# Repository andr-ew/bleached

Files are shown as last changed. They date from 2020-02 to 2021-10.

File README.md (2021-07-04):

## bleached
small/inexpensive 7-knob teensy midi controller. 

many thanks to [brian crabtree](https://vimeo.com/134631071) for sending me the original design & helping me add the teensy !!

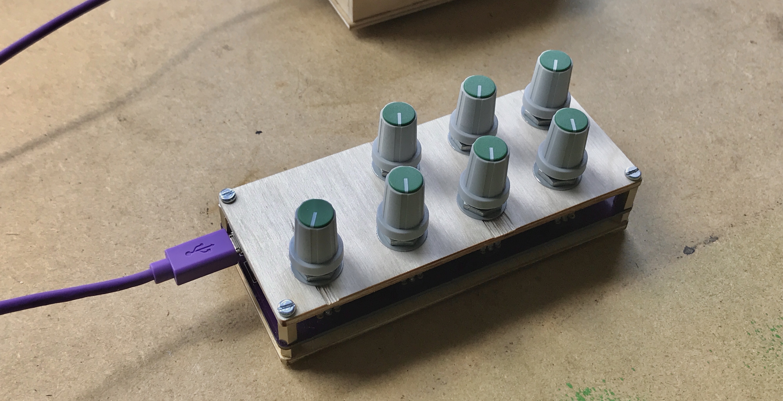
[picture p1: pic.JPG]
product image


## BOM

- [full BOM other than knobs](https://octopart.com/bom-tool/u6LfSTSI)
- [knobs from thonk (uk)](https://www.thonk.co.uk/shop/intellijel-black-knobs/) - [caps](https://www.thonk.co.uk/shop/sifam-caps/)

## Build

start with soldering all header pins to the underside of the teensy 3.2, reference the pic below for placement. the goal is to hit all of the power/ground pinouts along with the analog ins. solder short sides the two through-hole pins to the teensy. 

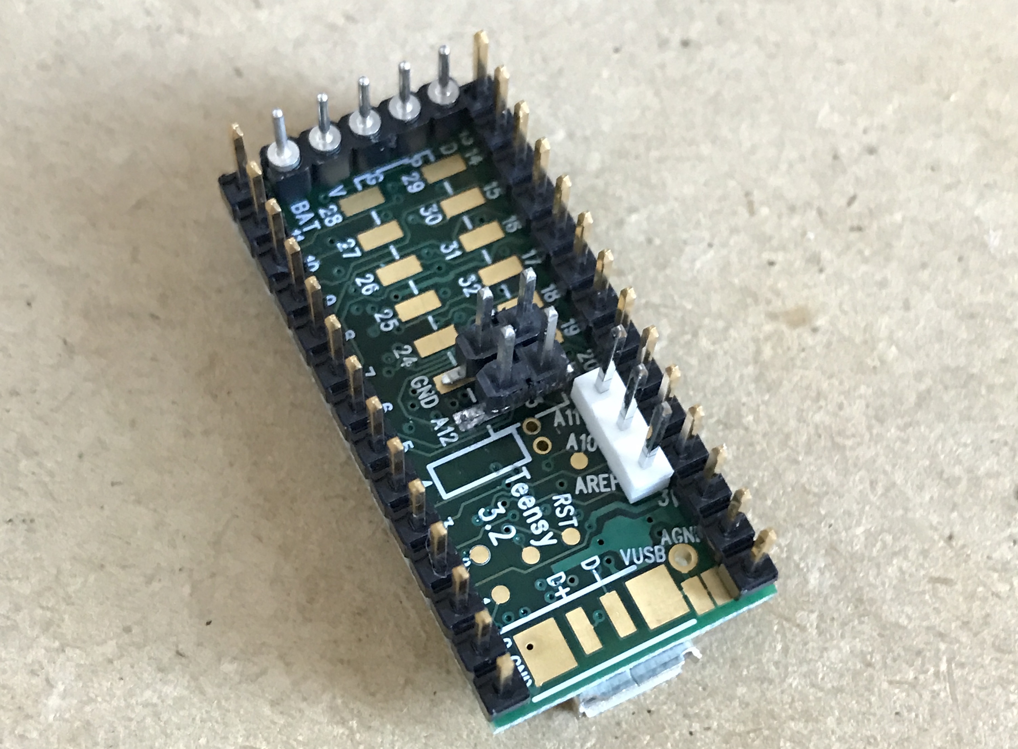
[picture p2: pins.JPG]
pins image


getting the surface mount pins in the right place is the trickiest part of this project. start with those (one leg at a time), use tweezers, and test placement on the board with the through-hole headers.

the rest should be pretty easy, solder all the other headers to the teensy, solder the teensy to the board (on the top / stencil side of the board), and solder every leg of each of the pots. load firmware & test once everything is soldered (although, at this point there's kinda no going back) - you can test your pots by loading the [test_inputs](./firmware/test_inputs/test_inputs.ino) sketch onto the board, and looking at the serial monitor window (Tools -> Serial Monitor) while twiddling the knobs. the firmware is an arduino project for use with [teensyduino](https://www.pjrc.com/teensy/teensyduino.html). 

next, add the metal standoffs, shorter ones on the bottom, taller ones on top. then screw in the panels. if you want the pots extra stable you can add the nuts and washers that come with the potentiometers. then plop on yr favorite knobs & yr golden !

## FAQ

q1) i don't have a 5-pin header for the top end of the teensy.
a2) you should have a 3-pin header, which should be used with the 3 middle pins.

q2) i get an error compiling the firmware, `'usbMIDI' was not declared in this scope`.
a2) set the USB type to 'Serial + MIDI' on the Tools -> USB Type menu.

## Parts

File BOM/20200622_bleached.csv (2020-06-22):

Qty | Line Item | Manufacturer | MPN | Octopart URL | Schematic Reference | Internal Part Number | Description | Total Qty (@ Batch Size: 1) | SKU | SKU | Packaging | Packaging | Unit Price (@ Batch Size: 1) | Unit Price (@ Batch Size: 1) | In Stock | In Stock | MOQ | MOQ | URL | URL | Distributor [Lowest Price (Overall)] | SKU [Lowest Price (Overall)] | Packaging [Lowest Price (Overall)] | Unit Price (@ Batch Size: 1) [Lowest Price (Overall)] | Line Total [Lowest Price (Overall)] | Batch Total [Lowest Price (Overall)] | In Stock [Lowest Price (Overall)] | MOQ [Lowest Price (Overall)] | URL [Lowest Price (Overall)] | Notes
 |  |  |  |  |  |  |  |  | Digi-Key | Mouser | Digi-Key | Mouser | Digi-Key | Mouser | Digi-Key | Mouser | Digi-Key | Mouser | Digi-Key | Mouser
1 | DEV-13736 | SparkFun | DEV-13736 | https://octopart.com/dev-13736-sparkfun-66786793 |  |  | teensy | 1 | 1568-1231-ND | 474-DEV-13736 | Bulk |  | 21.88 | 22.5 | 3468 | 0 | 1 | 1 | https://octopart.com/click/track?ai=8237&sig=0cd337c&sid=459&ppid=66786793&vpid=238615722&ct=offers | https://octopart.com/click/track?c=1&ai=8237&sig=036cc5a&sid=2401&ppid=66786793&vpid=460594265&ct=offers | Arrow.cn | DEV13736#SPARKFUN |  | 21.75 | 21.75 | 21.75 | 243 | 1 | https://octopart.com/click/track?ai=8237&sig=0c83821&sid=28928&ppid=66786793&vpid=617625825&ct=offers
2 | 22-28-4143 | Molex | 22-28-4143 | https://octopart.com/22-28-4143-molex-278217 |  |  | teensy header | 2 | WM50016-14-ND | 538-22-28-4143 | Bulk | Bulk | 0.99 | 0.76 | 528 | 87 | 1 | 1 | https://octopart.com/click/track?ai=8237&sig=0a93492&sid=459&ppid=278217&vpid=78026483&ct=offers | https://octopart.com/click/track?ai=8237&sig=0809279&sid=2401&ppid=278217&vpid=37674059&ct=offers | Heilind Electronics | MOL22-28-4143 |  | 0.43008 | 0.86016 | 0.86016 | 40 | 1 | https://octopart.com/click/track?ai=8237&sig=0ffd42f&sid=8539&ppid=278217&vpid=20581064&ct=offers
7 | RK09L1140A2U | ALPS | RK09L1140A2U | https://octopart.com/rk09l1140a2u-alps-7850070 |  |  | 6mm pots | 7 |  | 688-RK09L1140A2U |  | Tray |  | 1.49 |  | 959 |  | 1 |  | https://octopart.com/click/track?ai=8237&sig=0f03634&sid=2401&ppid=7850070&vpid=37992684&ct=offers | LCSC | C470448 | Tray | 1.015 | 7.1049999999999995 | 7.1049999999999995 | 36 | 1 | https://octopart.com/click/track?ai=8237&sig=06be386&sid=27971&ppid=7850070&vpid=625387208&ct=offers
1 | TSM-102-01-T-DV | Samtec | TSM-102-01-T-DV | https://octopart.com/tsm-102-01-t-dv-samtec-6823736 |  |  | teensy header | 1 | SAM10784-ND | 200-TSM10201TDV | Bulk | Bulk | 0.39 | 0.39 | 1554 | 2391 | 1 | 1 | https://octopart.com/click/track?ai=8237&sig=0a25a83&sid=459&ppid=6823736&vpid=417407955&ct=offers | https://octopart.com/click/track?ai=8237&sig=05d727c&sid=2401&ppid=6823736&vpid=493282502&ct=offers | Newark | 77P4639 |  | 0.118 | 0.118 | 0.118 | 2673 | 1 | https://octopart.com/click/track?ai=8237&sig=03440e8&sid=2402&ppid=6823736&vpid=47139229&ct=offers
2 | 22-03-2031 | Molex | 22-03-2031 | https://octopart.com/22-03-2031-molex-15103 |  |  | teensy header | 2 | 900-0022032031-ND | 538-22-03-2031 | Bulk | Bulk | 0.28 | 0.28 | 0 | 13233 | 1 | 1 | https://octopart.com/click/track?c=1&ai=8237&sig=093f6bf&sid=459&ppid=15103&vpid=587828796&ct=offers | https://octopart.com/click/track?ai=8237&sig=05e84a0&sid=2401&ppid=15103&vpid=37607239&ct=offers | Newark | 26H0648 |  | 0.086 | 0.172 | 0.172 | 9190 | 1 | https://octopart.com/click/track?ai=8237&sig=07890cb&sid=2402&ppid=15103&vpid=2936454&ct=offers
1 | M80-2260000B | Harwin | M80-2260000B | https://octopart.com/m80-2260000b-harwin-81780540 |  |  | bag of 12 2.5mm screws (need 8 ) | 1 | M80-2260000B-ND | 855-M80-2260000B | Bulk |  |  | 4.1 | 0 | 157 | 196 | 1 | https://octopart.com/click/track?c=1&ai=8237&sig=0720959&sid=459&ppid=81780540&vpid=519727817&ct=offers | https://octopart.com/click/track?ai=8237&sig=06e02d6&sid=2401&ppid=81780540&vpid=420857730&ct=offers | Mouser | 855-M80-2260000B |  | 4.1 | 4.1 | 4.1 | 157 | 1 | https://octopart.com/click/track?ai=8237&sig=06e02d6&sid=2401&ppid=81780540&vpid=420857730&ct=offers
4 | R25-1001002 | Harwin | R25-1001002 | https://octopart.com/r25-1001002-harwin-793354 |  |  | 10mm spacer | 4 | 952-2174-ND | 855-R25-1001002 | Bulk |  | 0.48 | 0.4 | 3373 | 2227 | 1 | 1 | https://octopart.com/click/track?ai=8237&sig=076609f&sid=459&ppid=793354&vpid=58220356&ct=offers | https://octopart.com/click/track?ai=8237&sig=0f1cbc1&sid=2401&ppid=793354&vpid=46536103&ct=offers | Newark | 99W9384 |  | 0.305 | 1.22 | 1.22 | 5478 | 1 | https://octopart.com/click/track?ai=8237&sig=06fc5f0&sid=2402&ppid=793354&vpid=90930922&ct=offers
4 | R25-3000502 | Harwin | R25-3000502 | https://octopart.com/r25-3000502-harwin-793850 |  |  | 5mm spacer | 4 | 952-3456-ND | 855-R25-3000502 | Bulk |  | 0.83 | 0.71 | 1584 | 3121 | 1 | 1 | https://octopart.com/click/track?ai=8237&sig=00d5341&sid=459&ppid=793850&vpid=417952346&ct=offers | https://octopart.com/click/track?ai=8237&sig=0a09265&sid=2401&ppid=793850&vpid=37615038&ct=offers | Farnell | 3225867 |  | 0.5963058666373657 | 2.385223466549463 | 2.385223466549463 | 721 | 1 | https://octopart.com/click/track?ai=8237&sig=0fb8c71&sid=819&ppid=793850&vpid=579539883&ct=offers

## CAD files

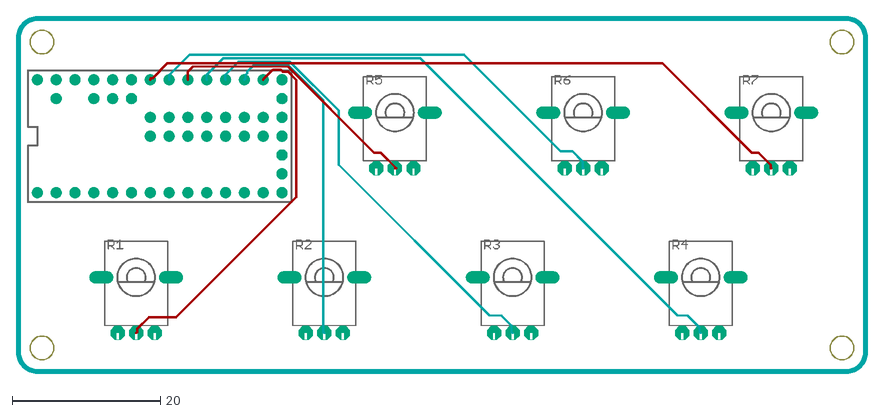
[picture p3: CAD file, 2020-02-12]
eagle/outline.dxf
114.9 x 48.2

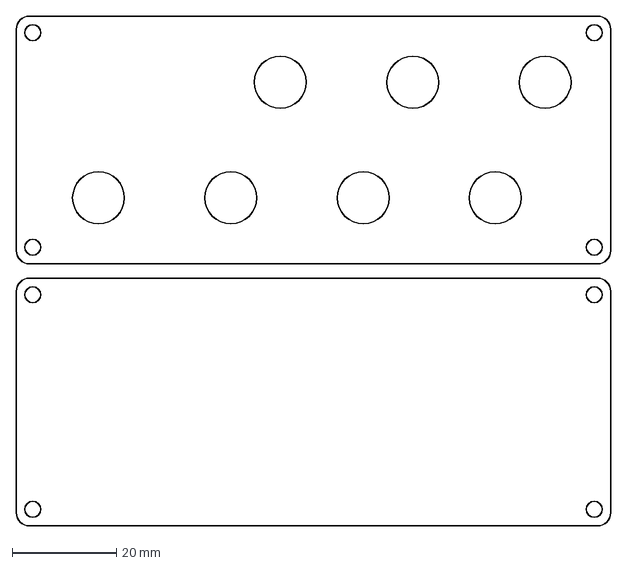
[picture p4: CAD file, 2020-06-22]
panels/top-and-bottom (width - 114.3mm).dxf
114.3 x 98.0 mm

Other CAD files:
panels/top-and-bottom.dxf

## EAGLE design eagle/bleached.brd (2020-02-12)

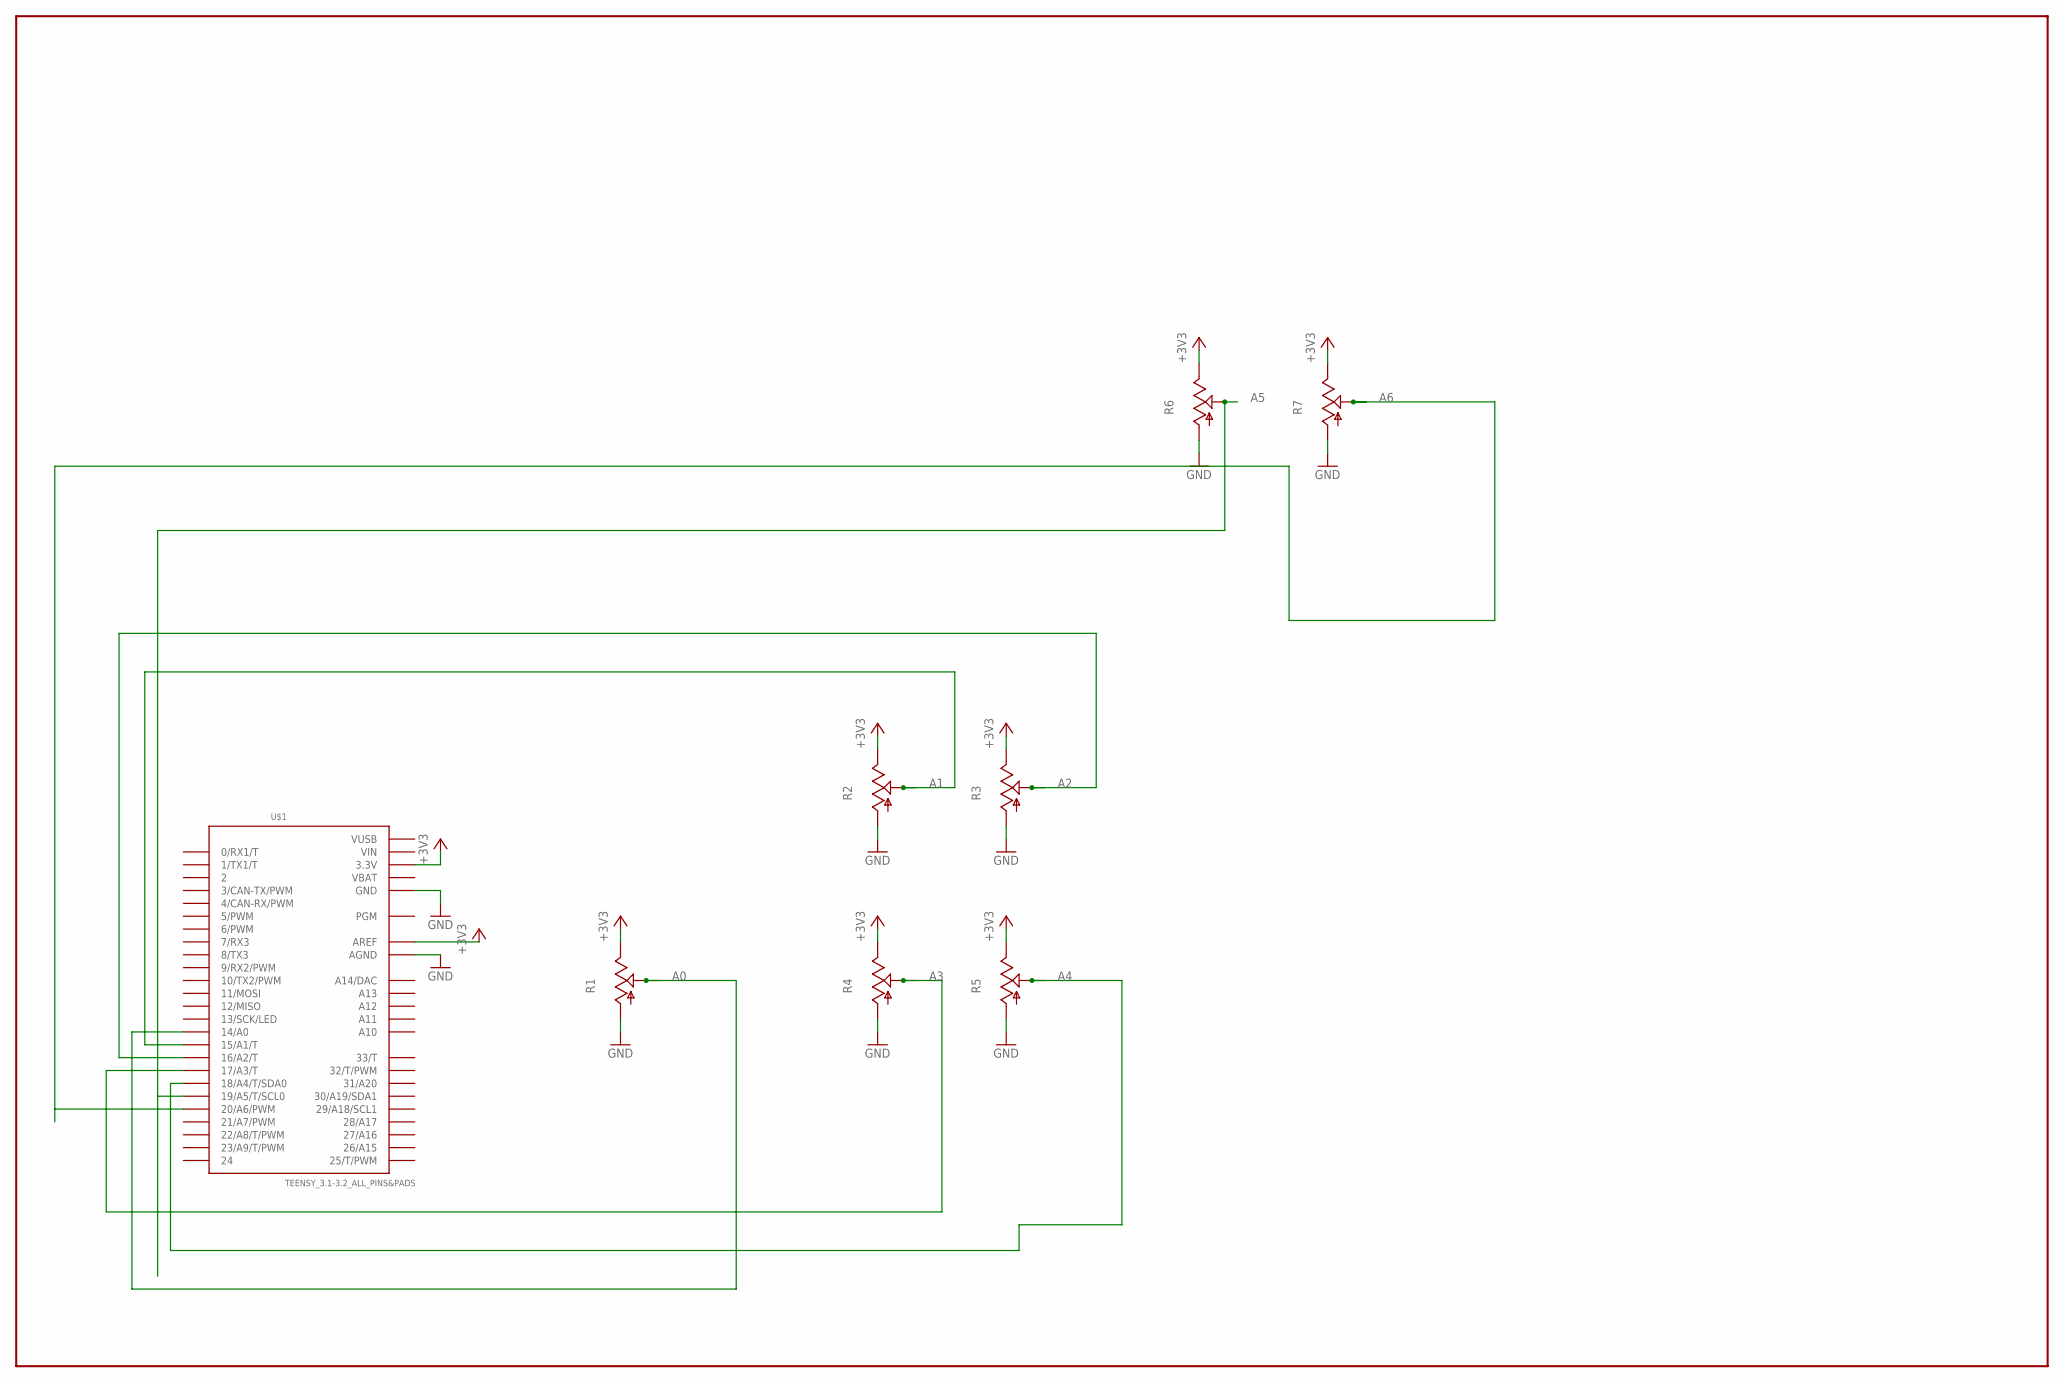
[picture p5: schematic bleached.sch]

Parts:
R1, R2, R3, R4, R5, R6, R7: SHAPES_POT-ALPS_POT_USVERTICAL_PS; SHAPES_POT-ALPS_ALPS_POT_VERTICAL_PS
U$1: TEENSY_3.1-3.2_ALL_PINS&PADS; TEENSY_3.0-3.2_ALL_PINS_&_PADS

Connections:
+3V3: R1.P$1 (E), R2.P$1 (E), R3.P$1 (E), R4.P$1 (E), R5.P$1 (E), R6.P$1 (E), R7.P$1 (E), U$1.3.3V, U$1.3.3V1 (3.3V), U$1.3.3V2 (3.3V), U$1.AREF
A0: R1.P$2 (S), U$1.14/A0
A1: R2.P$2 (S), U$1.15/A1 (15/A1/T)
A2: R3.P$2 (S), U$1.16/A2 (16/A2/T)
A3: R4.P$2 (S), U$1.17/A3 (17/A3/T)
A4: R5.P$2 (S), U$1.18/A4 (18/A4/T/SDA0)
A5: R6.P$2 (S), U$1.19/A5 (19/A5/T/SCL0)
A6: R7.P$2 (S), U$1.20/A6 (20/A6/PWM)
GND: R1.P$3 (A), R2.P$3 (A), R3.P$3 (A), R4.P$3 (A), R5.P$3 (A), R6.P$3 (A), R7.P$3 (A), U$1.AGND, U$1.GND, U$1.GND1 (GND), U$1.GND2 (GND)
VBAT: U$1.VBAT
VIN: U$1.VIN
VUSB: U$1.VUSB

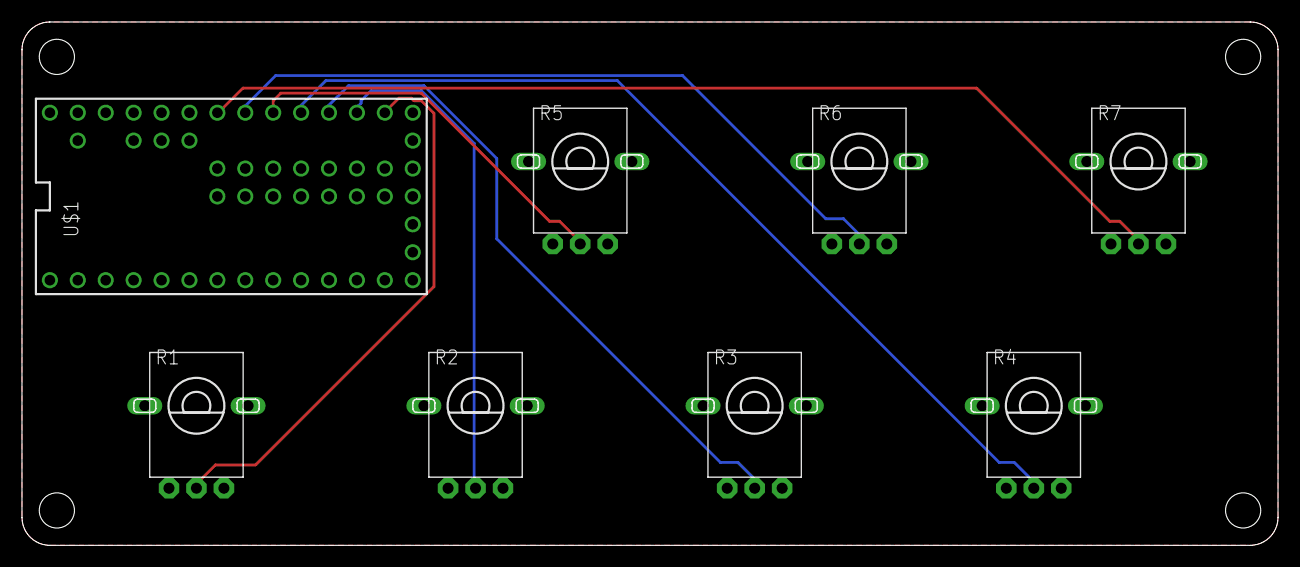
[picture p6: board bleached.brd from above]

Board: 2 copper layers, 114.3 x 47.6 mm, 8 parts (0 on the bottom side), 9 nets.

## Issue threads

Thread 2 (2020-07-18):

The BOM has M2 screws but the spacers are M2.5

andr-ew, 2020-07-18:
copy in the ones from here -> https://www.mouser.com/ProjectManager/ProjectDetail.aspx?AccessID=0237bf0204

Closed 2020-08-14.

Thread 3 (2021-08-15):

remove unneccesary headers

andr-ew, 2021-08-15:
only the outer left/right pins need to be soldered to the pcb so the other headers can be removed from the BOM & build guide

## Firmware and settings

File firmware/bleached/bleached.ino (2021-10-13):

/* Sonoclast pd knobs for TeensyLC
 
  * Modified by andrew for bleached (Teensy 3.2) 02/22/2019
 

   Copyright March 2019 - havencking@gmail.com

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
   The Sonoclast pd knobs is a MIDI CC controller designed particularly
   for use with pure data.  However it could be used to control any
   software that recognizes MIDI CC messages.  Customize the Control
   Channels below if you like.

   Compiling instructions:

   Follow these instructions to install the Arduino software and Tensyduino:
   https://www.pjrc.com/teensy/td_download.html

   In the Arduino software be sure to select the following:
   Tools > Board > Teensy3.2
   Tools > USB Type > Serial + MIDI
*/

// Map MIDI CC channels to knobs numbered left to right.
#define CC01  102
#define CC02  103
#define CC03  104
#define CC04  105
#define CC05  106
#define CC06  107
#define CC07  108

// Map the TeensyLC pins to each potentiometer numbered left to right.
#define POT01 0
#define POT02 1
#define POT03 2
#define POT04 3
#define POT05 4
#define POT06 5
#define POT07 6


// Use this MIDI channel.
#define MIDI_CHANNEL 1

// Send MIDI CC messages for all 7 knobs after the main loop runs this many times.
// This prevents having to twiddle the knobs to update the receiving end.
// 10,000 loops is roughly 10 seconds.
//#define LOOPS_PER_REFRESH 10000

// potentiometer read parameters
#define POT_BIT_RES         10 // 10 works, 7-16 is valid
#define POT_NUM_READS       32 // 32 works

// Track the knob state.
uint16_t prev_pot_val[7] = {0xffff,
                             0xffff, 0xffff, 0xffff, 0xffff, 0xffff, 0xffff
                            };

// an array of potentiometer pins
uint8_t pot[7] = {POT01,
                   POT02, POT03, POT04, POT05, POT06, POT07
                  };

// an array of CC numbers
uint8_t cc[7] = { CC01,
                  CC02, CC03, CC04, CC05, CC06, CC07
                 };

// Prevent jitter when reading the potentiometers.
// Higher value is less chance of jitter but also less precision.
const uint8_t nbrhd = 5;

// Count the number of main loops.
uint16_t loop_count = 0;

void setup() {
  // serial monitoring for debugging
  // Serial.begin(38400);

  // potentiometers
  analogReadResolution(POT_BIT_RES);
  analogReadAveraging(POT_NUM_READS);
}

void loop() {
  // Read each knob, and send MIDI CC only if the value changed.
  for (uint8_t i = 0; i < 7; i++) {
    uint16_t pot_val = analogRead(pot[i]);
    if ((pot_val < prev_pot_val[i] - nbrhd) ||
        (pot_val > prev_pot_val[i] + nbrhd)) {
      usbMIDI.sendControlChange(cc[i], pot_val >> (POT_BIT_RES - 7), MIDI_CHANNEL);
      prev_pot_val[i] = pot_val;
    }
  }

  // MIDI Controllers should discard incoming MIDI messages.
  // (reference: https://www.pjrc.com/teensy/td_midi.html)
  while (usbMIDI.read()) { ;; }

  // Periodically send MIDI CC for every knob so that the receiving end matches the knobs
  // even when changing pure data patches.
//  if (loop_count > LOOPS_PER_REFRESH) {
//    for (uint8_t i = 0; i < 7; i++) {
//      usbMIDI.sendControlChange(cc[i], analogRead(pot[i]) >> (POT_BIT_RES - 7), MIDI_CHANNEL);
//    }
//    loop_count = 0;
//  }
//  loop_count++;
}

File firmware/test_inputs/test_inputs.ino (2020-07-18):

 
void setup() {
  Serial.begin(31250);

  pinMode(A14, INPUT);    // sets the DAC as input
}

void loop() {
  // print the analog input values

  ////////// 4-POT ROW / COLUMN //////////

  Serial.print(analogRead(0));   // the lonely pot
  Serial.print('\t');

  Serial.print(analogRead(1));
  Serial.print('\t');

  Serial.print(analogRead(2));
  Serial.print('\t');

  Serial.print(analogRead(3));
  Serial.print('\t');

  ////////// 3-POT ROW / COLUMN //////////

  Serial.print(analogRead(4));
  Serial.print('\t');

  Serial.print(analogRead(5));
  Serial.print('\t');

  Serial.print(analogRead(6));

  Serial.println();
}

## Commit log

2020-06-22 fixed pot holes, added images
    [20200622_bleached.csv, top-and-bottom (width - 114.3mm).dxf]
2020-07-18 Added missing pot and removed non-existing ones
    [test_inputs.ino]
2021-10-07 read midi input, avoiding issues from always-full buffer
    [bleached.ino]

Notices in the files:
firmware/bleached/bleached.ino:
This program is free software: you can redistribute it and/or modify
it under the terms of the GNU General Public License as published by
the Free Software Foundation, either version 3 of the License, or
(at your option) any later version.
